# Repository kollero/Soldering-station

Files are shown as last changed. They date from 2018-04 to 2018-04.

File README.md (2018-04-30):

# Soldering-station
JBC compatible

T245B or similar

Uses a 24v 6-9A power supply that can be gotten cheaply from aliexpress.

Atmega328p and only exotic component is LMP8358, 1.3" oled display using u8g lib.

PCB was home made (toner transfered) so no real gerber files.

DIN type connector for the jbc, has to be changed to the t245b end, since couldn't find one that t245b would fit into directly.

temperature is measured in series with heater, so can rougly use 90% pwm max.
PID controlled, t245b uses IrRh temp table with 500x amplification to get correct temp readings 
overshoots a little but works fine after.

25 to 350 C degree tip heating takes about 4 seconds, and depending on tip around 150watts of power, 
so make sure power supply can handle it!

back panel has fused iec connector, also from aliexpress.
holder uses SH12a to hold the tip, and also has cheap brass tin collector.

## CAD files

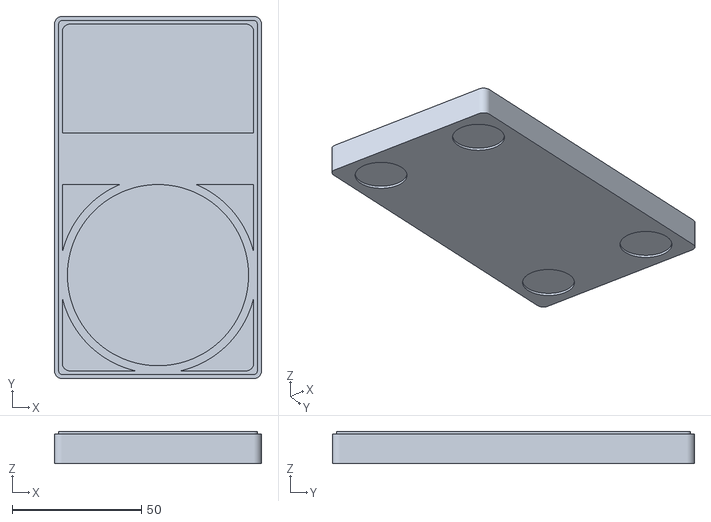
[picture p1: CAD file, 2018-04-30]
STL/holder/lower.STL
80.0 x 140.0 x 12.5

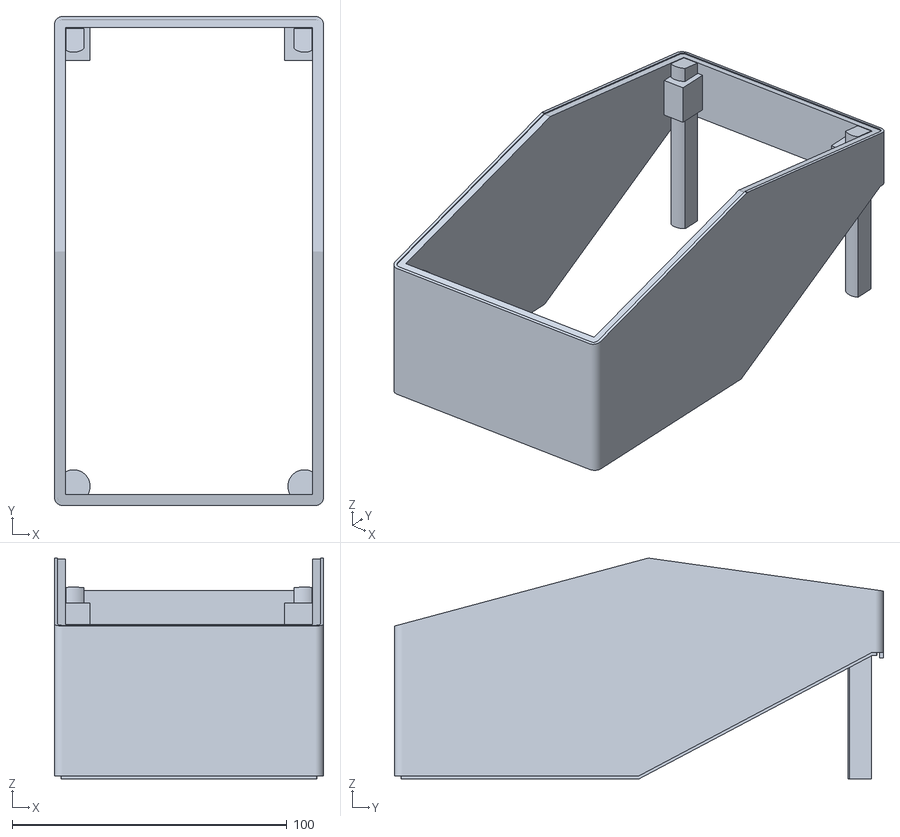
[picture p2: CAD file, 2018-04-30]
STL/top.STL
98.0 x 178.0 x 80.4

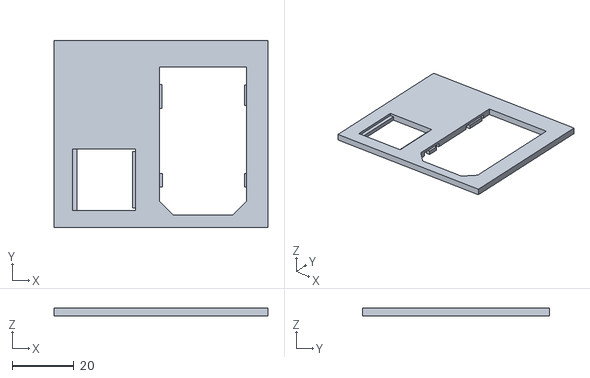
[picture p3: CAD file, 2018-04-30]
STL/back.STL
69.5 x 60.6 x 2.50

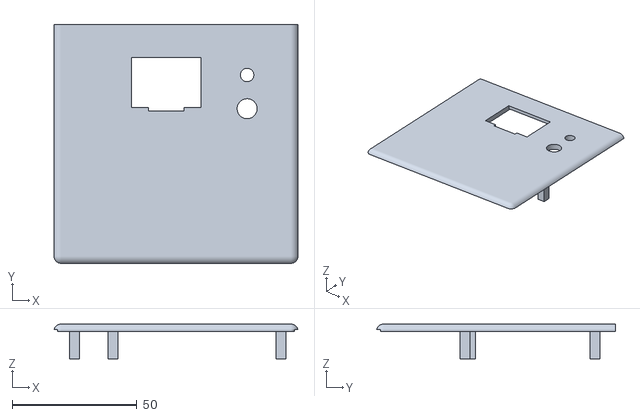
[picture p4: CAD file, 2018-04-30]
STL/control_panel.STL
97.8 x 95.7 x 14.0

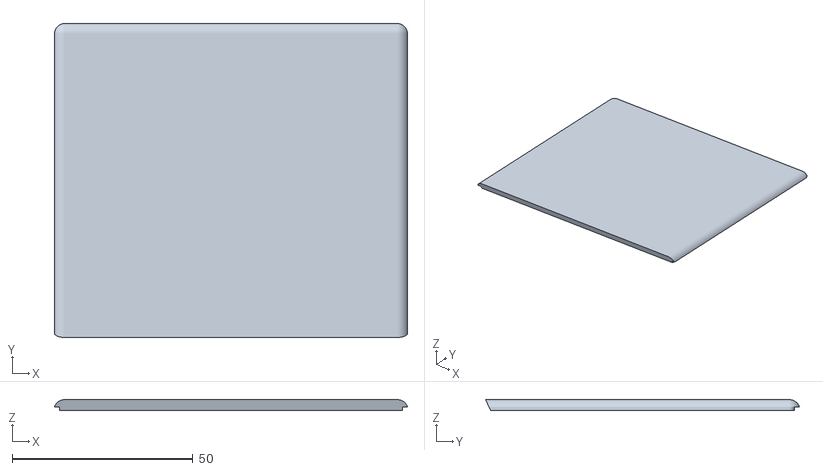
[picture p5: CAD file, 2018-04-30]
STL/roof.STL
97.8 x 86.9 x 3.00

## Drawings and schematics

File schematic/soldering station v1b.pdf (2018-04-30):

D

6 | 5 | 4 | 3 | 2 | 1

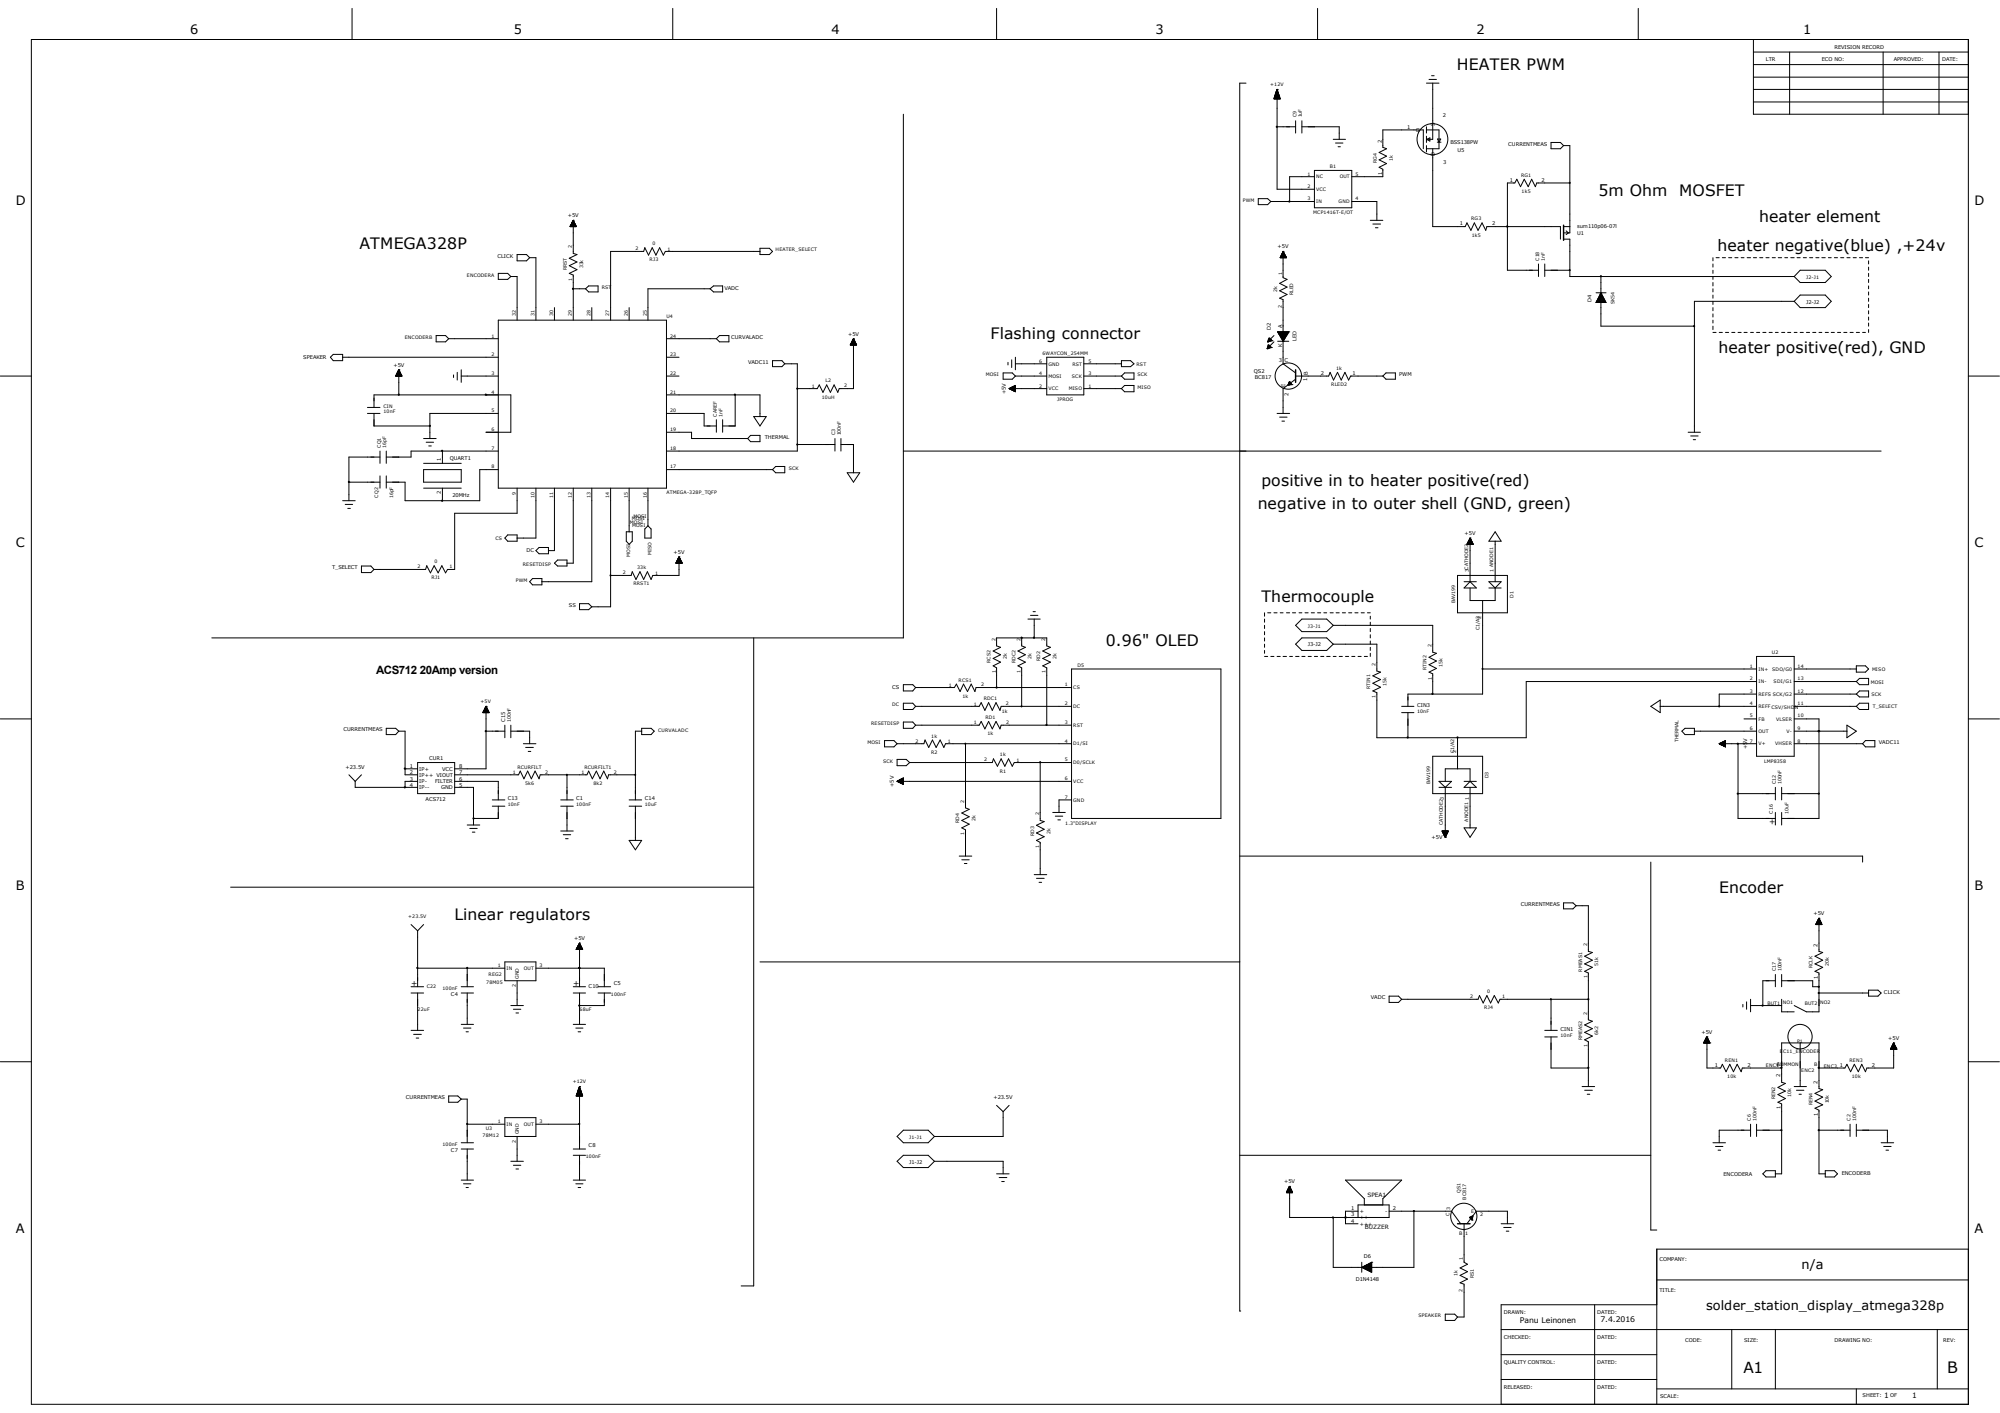
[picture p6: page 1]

REVISION RECORD

LTR | ECO NO: | APPROVED: | DATE:

heater positive(red), GND

positive in to heater positive(red)
negative in to outer shell (GND, green)

DRAWN: Panu Leinonen | DATED: 7.4.2016
CHECKED: | DATED: | CODE: | SIZE: A1 | DRAWING NO: | REV: B

QUALITY CONTROL: | DATED:

RELEASED: | DATED:

SCALE: | SHEET: 1 1 OF

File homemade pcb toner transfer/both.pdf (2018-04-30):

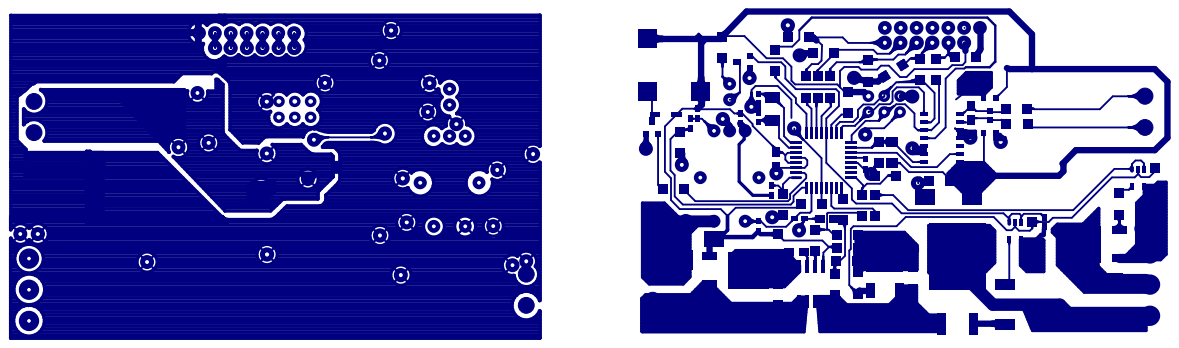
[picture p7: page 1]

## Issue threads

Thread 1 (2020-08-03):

Kollero / 焊台

JHS1211, 2020-08-03:
Hello, your welding machine is very good, but I didn't see T245 core connection, red terminals have connect GND, why the thermocouple connection at the end of the red and green? This is equal to connect GND on both ends of the thermocouple, can also have a role?

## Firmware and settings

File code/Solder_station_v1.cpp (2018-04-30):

/*
 * Solder_station_v1.cpp
 *
 * Created: 13.4.2016 21:26:34
 *  Author: Panu Leinonen
 */ 



#include <string.h>
#include <stdlib.h>
//#include <math.h>
#include <stdio.h>
#include <avr/pgmspace.h>
#include <avr/interrupt.h>
//#include <avr/wdt.h>
#include <avr/io.h>
#include <stdint.h>
//#include <stdbool.h>
#include <util/delay.h>
#include <avr/eeprom.h>

#include "u8g.h"
u8g_t u8g;

uint16_t EEMEM saved_temperature;
	
typedef struct{
	unsigned int bit0:1;
	unsigned int bit1:1;
	unsigned int bit2:1;
	unsigned int bit3:1;
	unsigned int bit4:1;
	unsigned int bit5:1;
	unsigned int bit6:1;
	unsigned int bit7:1;
} _io_reg;
#define REGISTER_BIT(rg,bt) ((volatile _io_reg*)&rg)->bit##bt

#define	ENCA REGISTER_BIT(PIND,2)
#define	ENCB REGISTER_BIT(PIND,3)
#define	ENCCLK REGISTER_BIT(PIND,1)

#define	INSTRUMENTATION_PORT REGISTER_BIT(PORTD,5)
#define INSTR_IDLE INSTRUMENTATION_PORT = 1   
#define INSTR_ACTIVE INSTRUMENTATION_PORT = 0

#define	HEATER_PORT REGISTER_BIT(PORTC,4)
#define HEATER_ACTIVE HEATER_PORT = 1
#define HEATER_IDLE HEATER_PORT = 0


#define	SPEAKER_PORT REGISTER_BIT(PORTD,4)
#define SPEAKER_IDLE SPEAKER_PORT = 0
#define SPEAKER_ACTIVE SPEAKER_PORT = 1

//I array size, total samples -1
#define TABLE_SIZE 41
//PID
#define P_val 30 //30
#define I_val 3 //3
#define D_val 50 //50

//max heater power
#define MAX_POWER 150
//how long to show the target temperature when encoder is rotated
#define TEMP_SHOW_TIME 4 //divided by 2
//how long to wait till saving new value to eeprom
#define TEMP_SAVE_TIME 10 //seconds divided by 2

//how long to show the saved sign on display
#define TEMP_SIGN_TIME 2 //seconds divided by 2
#define startmov 50 //disconnected sign tip

#define I_memory 40 //samples

#define OVERSAMPLING 4

//encoder look up table
const int8_t enc_LUT[17] ={0,-1,1,0,1,0,0,-1,-1,0,0,1,0,1,-1,0};
static uint8_t	old_AB = 0,
				old_click=0;

//volatiles
volatile int32_t	PID=0,
					encoder_value=0,
					err=0,
					err_old=0,
					P_err=0,
					D_err=0,
					mean_I_err[I_memory],
					mean_I_error=0.0,
					I_err=0.0;
					
volatile uint16_t	MAXIMUM_DUTY=1900;//1945 of 2048, 95% 1.3184ms left to do ADC etc. 20E6/(256*(2048-1945))=758Hz -> 1.3184ms
								
volatile uint16_t	seconds=0,
					temperature_adc[OVERSAMPLING],
					temperature_adc1=0,
					timer_1s=0,
					duty=0,													
					TARGET_TEMPERATURE=0,
					startxmov=startmov,
					temperature_adc_mean=0; 
				
volatile uint8_t	cmd_pulse=0,
					disconnected=0,
					keep_heater_off=0,
					clicked=0,
					show_temp=0,
					show_time=0,
					save_time=0,
					saved_sign=0,
					temp_value=0,
					speaker_now=0;
	

volatile long double 	temperature_value=0.0;
					


volatile uint16_t iji=0;
volatile double m=0.0;



//volatiles	
uint16_t	current_adc=0,
			current_adc1=0,
			voltage_adc=0,
			voltage_adc1=0,
			saved_temp=0,
			saved_temp_temp=0;
			
uint8_t		saved=1,
			times=0,
			spi_test=0,
			WRONG_AMPLIFICATION=0;
					
double	current_value=0.0,
		voltage_value=0.0,
		power_value=0.0,
		power_valuegah=0.0;
		
long double temperature_valuegah=0.0;		
uint16_t TARGET_TEMPERATUREgah=0;		

#include "Global_functions.h"
#include "Thermotable.h"

void u8g_setup() {
	// SCK: PORTB, Bit 5 --> PN(1,5)
	// MOSI: PORTB, Bit 3 --> PN(1,3)
	// CS: PD6 ->PN(3,6)
	// A0: PD7 --> PN(3,7) //DC!!
	// RST: PB0,  --> PN(1,0)
	// Arguments for u8g_InitHWSPI are: CS, A0, Reset
	//this one is SSD1306
		
	u8g_InitHWSPI(&u8g, &u8g_dev_ssd1306_128x64_hw_spi,PN(3,6),PN(3,7), PN(1,0));
	//u8g_InitHWSPI(&u8g, &u8g_dev_sh1106_128x64_hw_spi,U8G_PIN_NONE,PN(1,0), PN(3,7));
	// u8g_SetRot180(&u8g); //flip screen, if required
	//u8g_SetColorIndex(&u8g, 1);
}


void setup()
{	
	//pd1=encoders button (input), pd2= encoders B (input), pd3= encoders A (input),
	//pd4=speaker(out), pd5= instrumentation amp SPI select (active low)(out),
	//pd6=OLED displays SPI select(active low)(out), pd7=display D/C(out)
	DDRD=0b11110000;
	PORTD=0b01100000; 
		
	//pb0=reset display(out), pb1= solder tip PWM (out), pb2=ss(out and high),
	//pb3 =MOSI(out), pb4= MISO(in), pb5=sck(out)
	DDRB= 0b00101111;
	PORTB=0b00000100;
	
	//PC1=current in (in), pc2=vcc 24v (6.2/(51+6.2)) resistance divider (in)
	//PC4= non-volatile rheostat MCP4022 UD(out), PC5= non-volatile rheostat CS(out),
	DDRC =0b00110000;
	PORTC=0b00000000; //output 0 and input tri-state
	
	//ADC6 is thermal, ADC1 is current value, ADC2 is input voltage (24v)  
	ADMUX=0b01000110; //AVcc reference, 1nF cap in Aref pin, ADC6 thermal
	ADCSRA=0b11000111; //with 128 clk division from 20MHz is 156.25khz, should be between 50-200khz to get max resolution
	
	//ICR1 is the PWM counter max value, overflow(interrupt) at top, set (new) value in bot
	ICR1  = 2048; //max value of the counter
	OCR1A = 0; //zero at start
	TCCR1A = 0b10000010;  //fast PWM (mode 1110, ICR1 controls max period)
	TCCR1B = 0b00011100;  //prescale by 256 = total freq is 20MHz/(256*2048)= 38.14Hz < (100Hz/2) OK!
	TIMSK1 = 0b00000010;  //compare match A interrupts, then OCR1A=TCNT1 reads current temperature and calculates new value to be set for the PWM
		
	//OCR0A timer is for time calculation
	//output is 20MHz/(256*125)=1.6ms tick, 1sec every 625ticks
	OCR0A = 124; //runs to value 0:124, to get exact ms
	TCCR0A=0b00000010; //OCR0A compare match
	TCCR0B = 0b10000100; //force compare match A, prescaler to 256
	TIMSK0= 0b00000010; //masked compare match A
	//TCNT0 = 0x00; //set timer to 0
	
	//external interrupts
	EICRA=0b00000101; //any logical change generates interrupts
	EIMSK=0b00000011; //mask register
	//EIFR=0b00000000; //set interrupt flags to zero
	
	///PCINT17, pd1 or encoder button interrupt mask
	PCICR=0b00000100; //level change causes interrupt pins PCINT24-16
	PCMSK2=0b00000010; //PCINT17 masked
	
}

int main(void){
	setup();
	
	/*
	for (int i=0;i< 2;i++){
		delay_ms(1000); //wait 1 sec
		
	}
	*/
	//for hardware spi to work, have to redo these here
	DDRB = 0b00101111; //DDRB= 0b00101111;
	PORTB = 0b00000101; //output 0 and input tri-state
	//Hardware spi enabled, clk/16 mode, master mode, LMP8358 will require min 200ns for clk period
	SPCR=0b01010010; //0b01010001; //rising edge sampling
	SPSR=0b00000000;
	RWLMP8358(); //sets right values to the instrumentation amplifier
	//SPCR=0b01010000; //4x
	u8g_setup();
	
	
	//read eeprom at start
	int justtobesure3=0;
	while(1){
		justtobesure3++;
		if(eeprom_is_ready()==1) {
			//read values
			TARGET_TEMPERATURE=eeprom_read_word(&saved_temperature);
			break;
		}
		if (justtobesure3>=100){ //failed to read eeprom
			keep_heater_off=1;
			break;
		}
	}
	
	if(TARGET_TEMPERATURE <= 0 || TARGET_TEMPERATURE > 500){
		TARGET_TEMPERATURE=350;
	}
	
	for (int i=0;i< I_memory-1;i++){
		mean_I_err[i]=0;
	}
	

	cli(); //disable interrupts //was at beginning of system setup, start PWM can be glitchy if not next to each other
	sei(); //enable interrupts
	
	long double modulo=0;	
	char current1[6]={0,0,0,0,0};
	char voltage1[6]={0,0,0,0,0};
	char power1[6]={0,0,0,0,0};
	char temp1[6]={0,0,0,0,0};
	//char temp11[6]={0,0,0,0,0};
	char temp2[6]={0,0,0,0,0};
	//char temp21[6]={0,0,0,0,0};
		
	//char spi_testing[6]={0,0,0,0,0};	
	//intToStr(spi_test, spi_testing, 0);		
		
	char wtf[6]={0,0,0,0,0};
	char wtf2[6]={0,0,0,0,0};
	char wtf3[6]={0,0,0,0,0};
	
    while(1)
    {
		if(cmd_pulse==1){
			delay_ms(10);
			cmd_pulse=0;
						
			ADMUX=0b01000001; //check current ADC1
			ADCSRA |= (1 << ADSC);	 // start an ADC conversion
			while(ADCSRA & _BV(ADSC));    // wait until conversion is complete
			current_adc1=ADC;
			ADMUX=0b01000001; //check current ADC1
			ADCSRA |= (1 << ADSC);	 // start an ADC conversion
			while(ADCSRA & _BV(ADSC));    // wait until conversion is complete
			current_adc=(ADC+current_adc1)/2;
			//with ACS712 20 amp version
			//y=0.1v/A+2.5v, ADC value is 1024/5v=204.8/v
			//(adc-(1024/5v*2.5))*(1/(0.1*1024/5v))
			current_value=abs(current_adc-512)*0.048828125;//accuracy is 49mA  513
			if(current_value < 0 ){
				current_value=(double)0.0;
			}
			
			if (current_value > 8 && current_value < 20){
				current_value=(double)0.0;
				//over going value causes max duty cycle to be recalculated
				//MAXIMUM_DUTY=2048*0.9*((9-current_value)/current_value); 	
			}
			if (current_value >= 20){
				//short circuit
				keep_heater_off=1;	
			}
			ADMUX=0b01000010; //check input voltage ADC2
			ADCSRA |= (1 << ADSC);	 // start an ADC conversion
			while(ADCSRA & _BV(ADSC));    // wait until conversion is complete
			voltage_adc1=ADC;
			ADMUX=0b01000010; //check input voltage ADC2
			ADCSRA |= (1 << ADSC);	 // start an ADC conversion
			while(ADCSRA & _BV(ADSC));    // wait until conversion is complete
			voltage_adc=(ADC+voltage_adc1)/2;
			
			// voltage division from input with 6.2k/(6.2k+51k)
			// x*0.108391608391608*1024/5 =  22.198601398601397
			// 1/22.198601398601397=0.045047883064516
			voltage_value=(double)(voltage_adc*0.045047883064516);
			if(voltage_value>60){ //goodbye MOSFET
				voltage_value=(double)0.0;
			}
			
			power_value=(double)voltage_value*current_value;
			
			if(power_value>MAX_POWER+50){
				power_value=(double)0.0;	
			}
			if(clicked==1){ //save with click
				clicked=0;
				save_eeprom();
				saved_sign=TEMP_SIGN_TIME;
			}
			
			if( save_time == 0 && saved==0){
				saved=1;
				int justtobesure4=0;
				while(1){
					justtobesure4++;
					if(eeprom_is_ready()==1) {
						//read values
						saved_temp_temp=eeprom_read_word(&saved_temperature);
						break;
					}
					if(justtobesure4>=100){ //failed to read eeprom
						break;
					}
				}
				
				if(  TARGET_TEMPERATURE >= saved_temp_temp +5 || TARGET_TEMPERATURE+5 <= saved_temp_temp  ){ 
					save_eeprom();
					saved_sign=TEMP_SIGN_TIME;
					
				}
				
			}
			if( save_time > 0){
				save_time--;
				saved=0;
			}
			
			if( show_time>0){
				
				show_time--;
			}
			if(saved_sign >0){
				saved_sign--;
				
			}

			//intToStr(current_adc, current1, 3);						
			ftoa(current_value, current1, 3);
			ftoa(voltage_value, voltage1, 1);
					
			intToStr(temperature_adc_mean, wtf, 0);	
			intToStr(iji, wtf2, 0);
			ftoa(m, wtf3, 3);
					
		}
		
		
		memset(&temp2[0], 0, sizeof( temp2));
		TARGET_TEMPERATUREgah=TARGET_TEMPERATURE;
		intToStr(TARGET_TEMPERATUREgah, temp2, 0);
		
		memset(&temp1[0], 0, sizeof( temp1));
		temperature_valuegah=round(temperature_value);
		
		modulo=(uint16_t)temperature_valuegah % 5;
		if(modulo >=3){
			temperature_valuegah+=5-modulo;
		}
		else if(modulo <3){
			temperature_valuegah-=modulo;
		}

		ftoa(temperature_valuegah, temp1, 0);
		
		memset(& power1[0], 0, sizeof(power1));
		power_valuegah=power_value;
		ftoa(power_valuegah, power1, 0);
			
		

		u8g_FirstPage(&u8g);
		do{	//x,y
			//LCD_clear();
			//u8g_Delay(50);
			//disconnected_sign_moving();
						
			if(disconnected==1){
			//please check connection
				u8g_SetFont(&u8g, u8g_font_fur25);
				//LCD_clear();
				//u8g_Delay(50);
				//disconnected_sign_moving();
				u8g_DrawStr(&u8g, 19, 41,"check");
				u8g_DrawStr(&u8g, 0, 61,"connect");
			}
			else if(disconnected==0){
				
				if(saved_sign >0){ 
					save_sign();
				}
				
				u8g_SetFont(&u8g, u8g_font_7x13);
				//u8g_DrawStr(&u8g, 58, 13,current1);
				//u8g_DrawStr(&u8g, 8, 13,wtf);
				//	u8g_DrawStr(&u8g, 50, 13,wtf2);
				//u8g_DrawStr(&u8g, 8, 13,voltage1);
				//u8g_DrawStr(&u8g, 18, 13,"target:");
				//u8g_DrawStr(&u8g, 68, 13,temp2);
				
				u8g_SetFont(&u8g, u8g_font_fur30n); //54x30 pixels
				
				if( show_time>0){
					show_temp=0;					
					//strncpy(temp2,temp1,6);			
					if(TARGET_TEMPERATUREgah>= 100){
						
						u8g_DrawStr(&u8g, 18, 49,  temp2);				
						//delay_ms(30);
					}
					else if(TARGET_TEMPERATUREgah < 100 && TARGET_TEMPERATUREgah >= 10){
					
						u8g_DrawStr(&u8g, 42, 49,  temp2);
						//delay_ms(30);
					}
					else if(TARGET_TEMPERATUREgah < 10){
						u8g_DrawStr(&u8g, 66, 49,  temp2);
					}	
				}		
							
				else if(show_temp==0 && show_time==0){
					
					if(temperature_valuegah >= 100 ){//&& temperature_value < 1000){	
						u8g_DrawStr(&u8g, 18, 49,  temp1);
						//delay_ms(30);	
					}
					else if(temperature_valuegah < 100 && temperature_valuegah >= 10){
						//u8g_SetDefaultBackgroundColor(&u8g);
						//u8g_DrawBox(&u8g,18,19,25,30); //clears first digit
						//u8g_SetDefaultForegroundColor(&u8g);
						//cli(); //disable interrupts //was at beginning of system setup, start PWM can be glitchy if not next to each other
						u8g_DrawStr(&u8g, 42, 49,  temp1);
						//delay_ms(30);					
						//sei(); //enable interrupts
					}
					else if(temperature_valuegah < 10){
						u8g_DrawStr(&u8g, 66, 49,  temp1);
					}
					//u8g_SetFont(&u8g, u8g_font_7x13);
					//u8g_DrawStr(&u8g, 8, 13,wtf);
			
					
					//u8g_DrawStr(&u8g, 30, 13,wtf2);
					//u8g_DrawStr(&u8g, 60, 13,wtf3);
					
				}
				//u8g_SetFont(&u8g, u8g_font_7x13);
				//u8g_DrawStr(&u8g, 60, 13,spi_testing);	
				
					
				u8g_SetFont(&u8g, u8g_font_fur25);
				u8g_DrawStr(&u8g, 90, 48,  "°C");
			
				u8g_SetFont(&u8g, u8g_font_7x13);	
				power_scale();
				if(power_valuegah < 10){
					u8g_DrawStr(&u8g, 113, 63, power1);
				}
				else if(power_valuegah < 100 && power_valuegah >= 10){
					//u8g_SetDefaultBackgroundColor(&u8g);
					//u8g_DrawBox(&u8g,99,50,7,13); //clears first digit
					//u8g_SetDefaultForegroundColor(&u8g);
					u8g_DrawStr(&u8g, 106, 63, power1);
					
				}
				else if( power_valuegah >= 100){
				
					u8g_DrawStr(&u8g, 99, 63, power1);
					
				}
				u8g_DrawStr(&u8g, 121, 63, "w");	
				}
			
	
		} while ( u8g_NextPage(&u8g) );
		u8g_Delay(330);
	}
	
		
				
}

//OCR1A is double buffered so can set a new value anytime, ICR1 is not double buffered
ISR(TIMER1_COMPA_vect){ //Output Compare A Match Interrupt
HEATER_IDLE; //don't use unless testing
delay_us(800); //wait at least xxx us for thermocouple voltage to get normal
//checking temp and adjusting PWM takes around 800us
ADMUX=0b01000110; //AVcc reference, 1nF cap in Aref pin, ADC6 thermal
temp_value=0;
temperature_adc_mean=0;
while(temp_value < OVERSAMPLING){
	delay_us(1);	
	ADCSRA |= (1 << ADSC);	 //start an ADC conversion
	while(ADCSRA & _BV(ADSC));    //wait until conversion is complete
	temperature_adc_mean+=ADC;
	temp_value++;
}
temperature_adc_mean=round(temperature_adc_mean/OVERSAMPLING);

if( keep_heater_off==1 || temperature_adc_mean > 1000 || WRONG_AMPLIFICATION==1){
	duty=0;
	disconnected=1;
	OCR1A=duty;
}
else if( keep_heater_off==0 && WRONG_AMPLIFICATION==0 ){ 
	disconnected=0;
	//calculate temperature	
	temperature_value = dsp_lookup(IrRh500amp,temperature_adc_mean);
		
	//temperature_value =abs(temperature_value);
	//temperature_value+=25; //due offset voltage temperature drift compensation in op amp 
	
	//PID	
	err_old=err; //save old value
	err=(int32_t)TARGET_TEMPERATURE-temperature_value; //calculate the temperature difference
	P_err=err; //Proportional is directly the difference times P_val (bang bang value)
	
	mean_I_err[I_memory-1]=(int32_t)err;
	mean_I_error=0;
	for (int i=0;i< I_memory-1;i++){
		mean_I_err[i]=(int32_t)mean_I_err[i+1];		
		mean_I_error+=(int32_t)mean_I_err[i];
	}	
	mean_I_error+=(int32_t)err;
		
	I_err=(int32_t)mean_I_error;
	
	//I_err+=err_old; //integral is all the previous values summed (this will cause it to overshoot a lot)
	D_err=(int32_t)err-err_old;	//derivative is the difference between earlier and this one (helps lower overshooting)
	PID=(int32_t)P_val*P_err + I_val*I_err + D_val*D_err;
	if(PID > MAXIMUM_DUTY){ //95% duty cycle max, recalculate here if current drain is over 9A
		PID=MAXIMUM_DUTY;
	}
	else if(PID < 0){ 
		PID=0;
	} 
	duty=(uint16_t)PID;
	OCR1A=duty;

	if((temperature_value <= TARGET_TEMPERATURE+5 && temperature_value +5 >= TARGET_TEMPERATURE ) && speaker_now==0){
		speaker_now=1;
		SPEAKER_ACTIVE;
		delay_ms(3);
		SPEAKER_IDLE;
		delay_ms(3);
		SPEAKER_ACTIVE;
		delay_ms(3);
		SPEAKER_IDLE;		
	}
}

HEATER_ACTIVE;
}

ISR(TIMER0_COMPA_vect) { //1.6ms tick 1s with 625 rounds for 1sec

timer_1s++;
if(timer_1s == 313){
	cmd_pulse=1; //time to refresh display
}

if(timer_1s >= 625){ //1 seconds has passed
	cmd_pulse=1; //time to refresh display
	timer_1s=0; //zero the timer if 1 second has been reached
	seconds++; //increase if under 59 sec
	if(seconds > 59){
		seconds=0; //zero if
		//one minute has passed here
	}
}
}

//external interrupts for encoder
ISR(INT0_vect) { //encoder A
old_AB <<= 2;                //remember previous state
old_AB |= ( ENCA | ENCB<<1 );  //add current states
TARGET_TEMPERATURE+=enc_LUT[( old_AB & 0x0f )];
if(TARGET_TEMPERATURE > 1000 || TARGET_TEMPERATURE <0 ){ //if negative
	TARGET_TEMPERATURE=0;
}
else if(TARGET_TEMPERATURE <= 1000){
	show_temp=1;
	show_time=TEMP_SHOW_TIME;
	save_time=TEMP_SAVE_TIME;
}

}

ISR(INT1_vect) { //encoder B
old_AB <<= 2;                //remember previous state
old_AB |= ( ENCA | ENCB<<1 );  //add current states
//old_AB |=( ENCA>>1 | ENCB>>3 );  //add current states
TARGET_TEMPERATURE+=enc_LUT[( old_AB & 0x0f )];
if(TARGET_TEMPERATURE > 1000 || TARGET_TEMPERATURE <0){ //if negative
	TARGET_TEMPERATURE=0;
}	
else if(TARGET_TEMPERATURE <= 1000){
show_temp=1;
show_time=TEMP_SHOW_TIME;
save_time=TEMP_SAVE_TIME;
}

}
//clicker interrupt
ISR(PCINT2_vect){
old_click <<= 1; 
old_click |=  ENCCLK;  //add current state
	if(old_click&0x02){ //if pulled down
		 //clicked
		 clicked=1;
		 show_temp=1;
		 show_time=TEMP_SHOW_TIME;
	}	          
}
